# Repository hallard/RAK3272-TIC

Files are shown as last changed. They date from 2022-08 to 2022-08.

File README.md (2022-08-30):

# RAK3272 TIC (Teleinfo) LoRaWAN Shield

This shield is used to get French energy meter called Teleinfo data with WisDuo LoRaWAN RAK3272 SIP Breakout board:

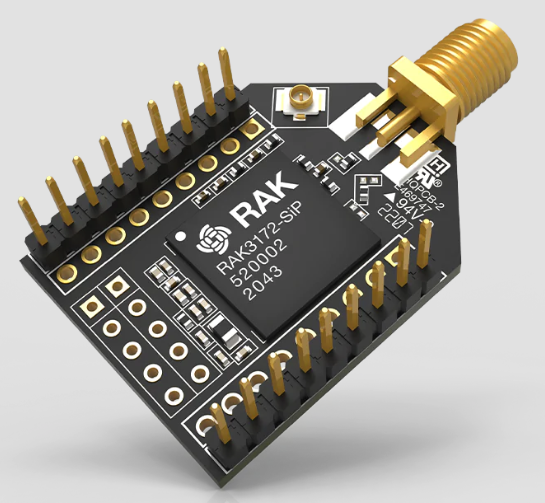
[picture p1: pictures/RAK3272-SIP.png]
&nbsp;

# Detailed Description

**V1.0**

- On Board 3.3V regulator used when powering thru batteries (Vin > 3.6V)
- Low Power Mode option driving some GPIO to disable TIC
- Led to indicated TIC reception signal
- User Red and Green Led 
- User button (pull down)
- On board I2C Pullups (4K7)
- Footprint for Battery connector 
- QWICC / Stemma standard connector

:warning: Despite the fact that RAK3272-SIP Breakout announced as xBee format, this is far from the case because:

- xBee as 16 pins on the header this one 18 pins
- xBee pinout is totally different (power and other)
- least but not least, headers spacing of external raws of RAK3272 are different than xBee.

So in V1.0 version of my shield you will need to bend headers of RAK3272 and shield so you can plug it, that's a shame.

Anyway, if you're designing shield for RAK3272 don't take xBee spacing format for external headers, it won't fit 

# Pinout

Look at the schematics for more informations, easy to understand. Wiring on the RAK3272 Teleinfo shield is as follow:

| Pin Function | RAK3272 | STM32WL |
|  :--- |  :---: |  :---:  |
| TIC Rx | UART1_RX  | PB7 |
| TIC Enable | SPI1_CLK  | PA5 | 
| Led TIC | PA8 | PA8 | 
| Led Red | SPI1_MISO | PA6 | 
| Led Green | SPI1_MOSI | PA7 | 
| Button | SPI1_NSS  | PA4 | 
| I2C SDA | I2C2_SDA  |  PA11 |
| I2C SDL | I2C2_SCL  |  PA12 |

:warning: Button is `boot0` button, to avoid adding one more button for user, I wired Boot0 to `PA4` to we can read button state, but since it's `boot0` it has pulldown resistor and it is active High.

To enable reading Téléinfo you need:

- Drive High ping `PA5` (mandatory)
- Drive High ping `PA8` (to eable TIC Led to blink on data reception on Serial)
- Read Teleinfo on `UART1_RX` (`PB7`)

# Schematics

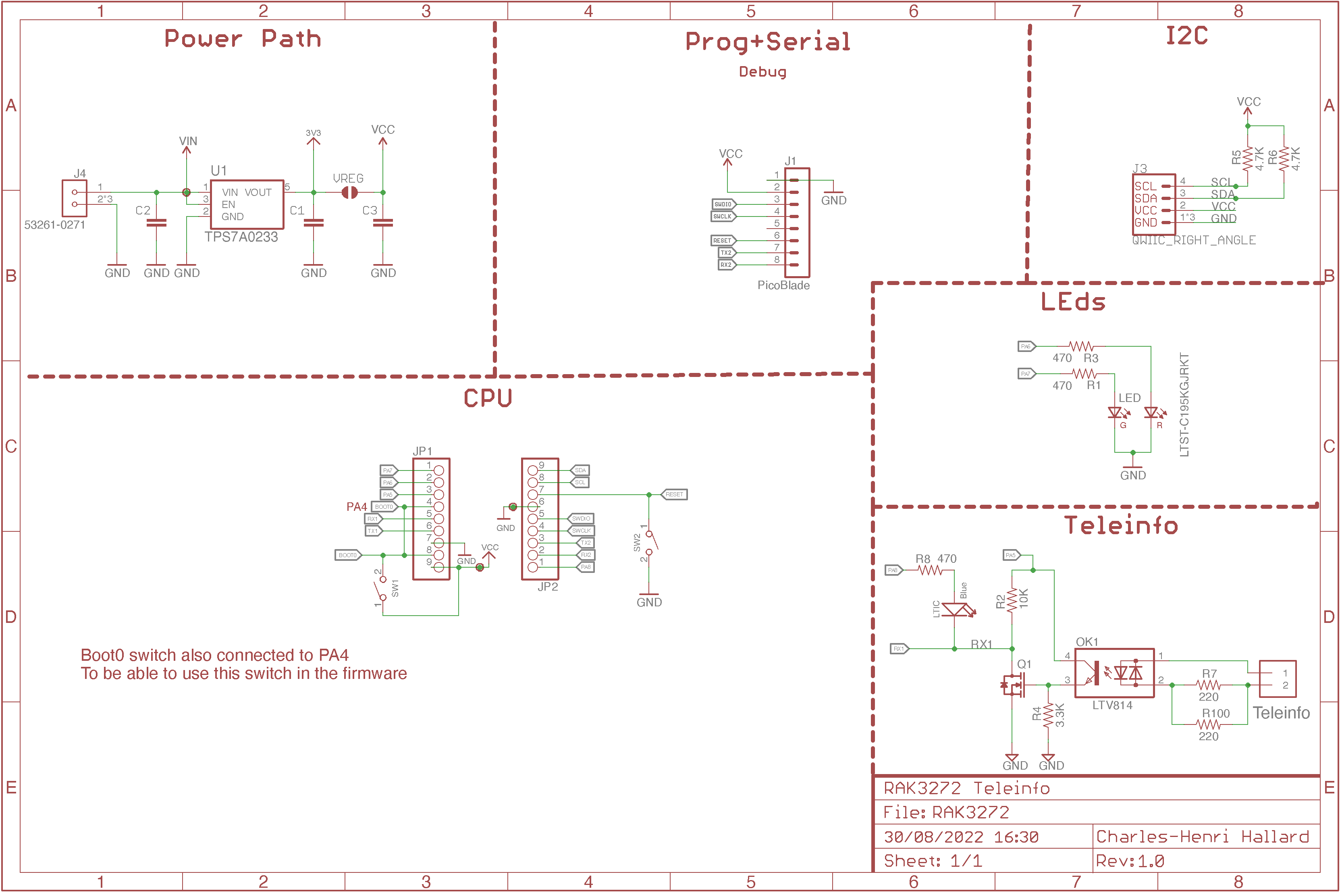
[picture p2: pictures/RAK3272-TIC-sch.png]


# Boards

## Assembled (V1.0)

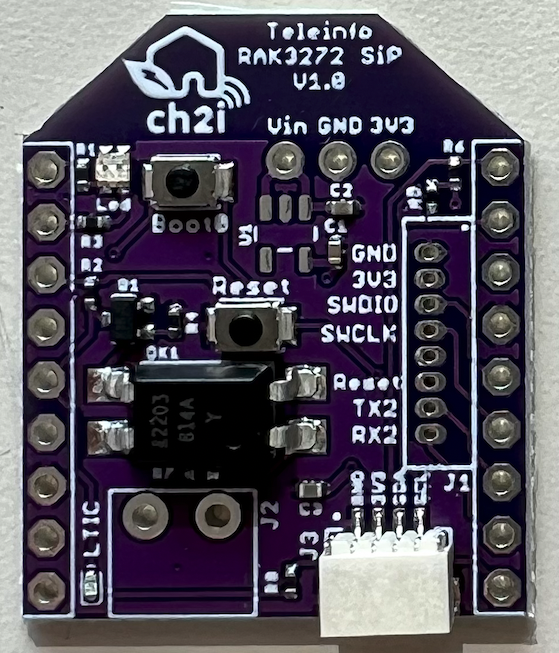
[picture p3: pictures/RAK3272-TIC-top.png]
&nbsp;&nbsp;
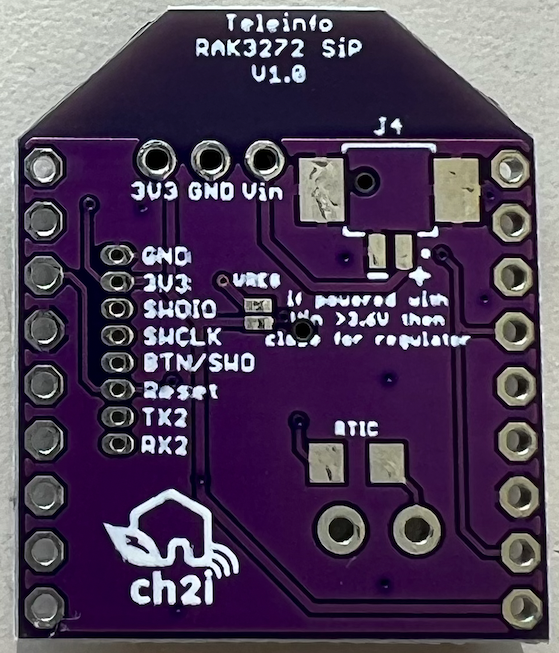
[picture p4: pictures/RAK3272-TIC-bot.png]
Bottom


## Shield Plugged on RAK3272 SIP Breakout

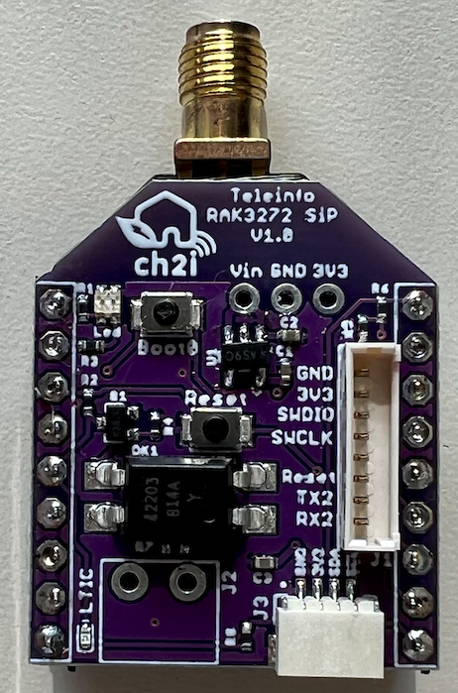
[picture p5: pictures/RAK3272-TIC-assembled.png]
RAK3272 Teleinfo Assembled Top
&nbsp;

# Firmware 

You can write your own and use with [LibTeleinfo](https://github.com/hallard/LibTeleinfo) library I wrote if you want to get rid of driving teleinfo stuff (chekout some [examples](ttps://github.com/hallard/LibTeleinfo/tree/master/examples)).

To Be Completed

## I2C 

You can add fancy I2C display or even I2C sensors, there is a Stemma QWIIC connector on board. Since I2C VCC is conencted to 3.3V, your I2C should works in 3.3V or 5V or 5V ones (They all have level shifter since majorty of sensors works at 3.3V)

# Support and discussion

If you have any issue or just want to discuss on this project, please use community [forum](https://community.ch2i.eu/category/19/wemos-teleinfo)

# License

   

This work is licensed under a [Creative Commons Attribution-NonCommercial 4.0 International License](http://creativecommons.org/licenses/by-nc/4.0/)    
If you want to do commercial stuff with this project, please contact [CH2i company](https://ch2i.eu/en#support) so we can organize an simple agreement.

# Lazy building your own? 

You can order this shield fully assembled with some extra on tindie (soon, may be)



# Misc

See news and other projects on my [blog][2] 
 
[2]: https://hallard.me

[20]: https://store.rakwireless.com/products/wisduo-breakout-board-rak3272-sip
[21]: https://docs.rakwireless.com/Product-Categories/WisDuo/RAK3272-SiP-Breakout-Board/Datasheet
[22]: https://www.smart-prototyping.com/Mini-D1-PRO-Development-Board-ESP8266-4M-16M
[23]: https://www.az-delivery.de/fr/products/esp32-d1-mini
[24]: https://www.tindie.com/products/25467/

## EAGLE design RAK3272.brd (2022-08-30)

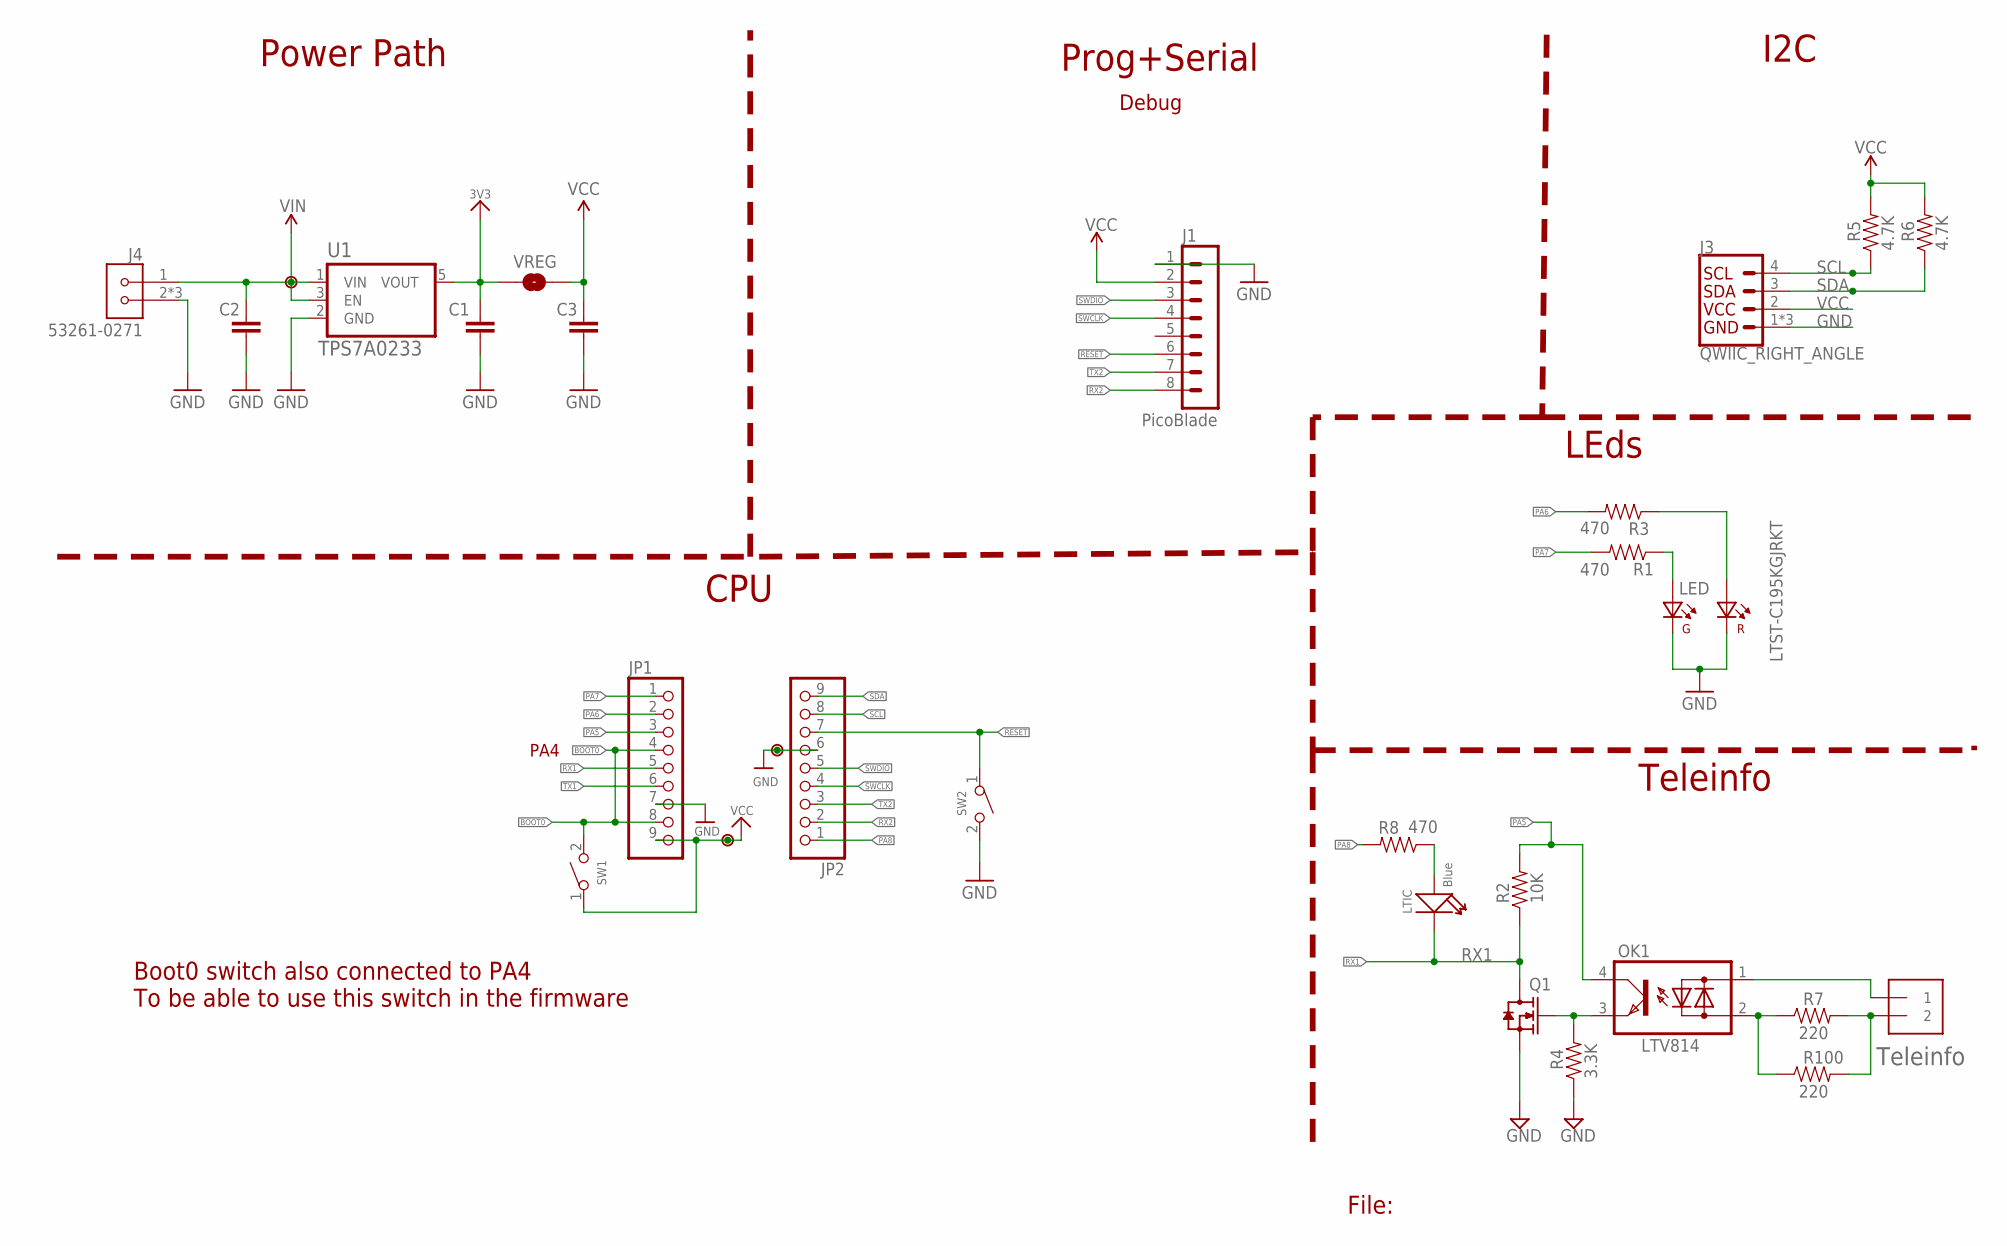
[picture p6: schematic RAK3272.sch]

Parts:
C1, C2, C3: 1.0uF; 0402-CAP-OK
J1: PicoBlade; 53047-0810
J2: 1X2-3.5MM
J3: QWIIC_RIGHT_ANGLE; JST04_1MM_HORI
J4: 53261-0271; MOLEX_53261-0271
JP1, JP2: PINHD-1X9; 1X09-BIG
LED: LTST-C195KGJRKT; LTST-BILED-15X16
LTIC: Blue; LED-0402
OK1: LTV814; DIL4-SMD
P1, P2, P3: PADNORMAL; PAD
Q1: CJ2302; SOT-323-3
R1, R3, R8: 470; 0402-RES
R2: 10K; 0402-RES
R4: 3.3K; 0402-RES
R5, R6: 4.7K; 0402-RES
R7: 220; 0402-RES
R100: 220; 1206
SW1, SW2: B3U-1000P-2P-SMD; C498294
U1: TPS7A0233; SOT95P280X145-5N
VREG: JUMPER-SMT_2_NO_NO-SILK; SMT-JUMPER_2_NO_NO-SILK

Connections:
3V3: C1.1, U1.5 (VOUT), VREG.2
BOOT0: JP1.4, JP1.8, SW1.2
GND: C1.2, C2.2, C3.2, J1.1, J3.1, J3.NC1 (1), J3.NC2 (1), J4.2, J4.P1 (2), J4.P2 (2), JP1.7, JP2.6, LED.P$3 (K1), LED.P$4 (K2), P2.1, Q1.2 (S), R4.1, SW2.2, U1.2 (GND)
unnamed: LED.P$2 (A2), R3.1
unnamed: LED.P$1 (A1), R1.1
unnamed: OK1.2 (AC2), R7.1, R100.1
unnamed: J2.1, OK1.1 (AC1)
unnamed: J2.2, R7.2, R100.2
unnamed: OK1.3 (E), Q1.1 (G), R4.2
unnamed: LTIC.+, R8.1
PA5: JP1.3, OK1.4 (C), R2.2
PA6: JP1.2, R3.2
PA7: JP1.1, R1.2
PA8: JP2.1, R8.2
RESET: J1.6, JP2.7, SW2.1
RX1: JP1.5, LTIC.-, Q1.3 (D), R2.1
RX2: J1.8, JP2.2
SCL: J3.4, JP2.8, R5.1
SDA: J3.3, JP2.9, R6.1
SWCLK: J1.4, JP2.4
SWDIO: J1.3, JP2.5
TX1: JP1.6
TX2: J1.7, JP2.3
VCC: C3.1, J1.2, J3.2, JP1.9, P3.1, R5.2, R6.2, SW1.1, VREG.1
VIN: C2.1, J4.1, P1.1, U1.1 (VIN), U1.3 (EN)

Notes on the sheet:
File:
Teleinfo
I2C
LEds
Power Path
CPU
Prog+Serial
Debug
Boot0 switch also connected to PA4 To be able to use this switch in the firmware
PA4

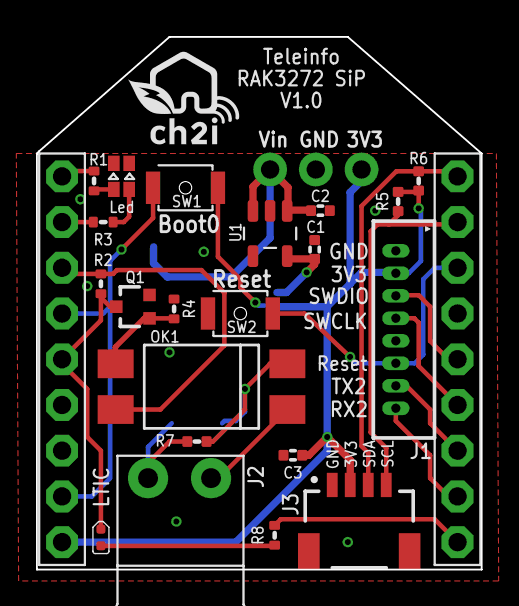
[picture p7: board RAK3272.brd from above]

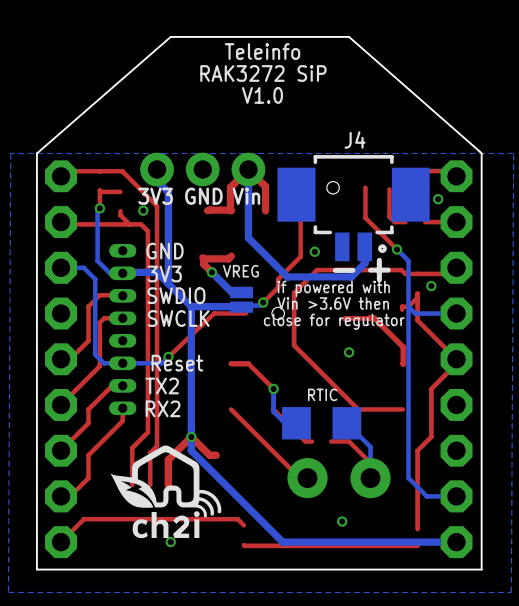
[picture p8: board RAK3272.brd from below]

Board: 2 copper layers, 24.7 x 29.6 mm, 31 parts (4 on the bottom side), 24 nets.

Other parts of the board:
$$U$1: LOGO_C2I_015
U$100: LOGO_C2I_015

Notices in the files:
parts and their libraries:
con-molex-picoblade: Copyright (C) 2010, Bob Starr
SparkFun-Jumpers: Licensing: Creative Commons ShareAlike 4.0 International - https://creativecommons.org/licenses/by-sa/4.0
